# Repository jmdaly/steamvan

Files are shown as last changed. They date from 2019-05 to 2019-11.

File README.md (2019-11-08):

# SteamVan PCB

The SteamVan was developed as a MiniVan-compatible PCB based on an STM32MCU. It
does not support hot swap sockets, and it is designed such that the switches
are oriented such that the LEDs are South-facing.

## Overview

The SteamVan aims to meet the following design goals:

* Switches oriented such that the LEDs are South-facing, for
  compatibility with Cherry profile keycaps.

* USB Type-C support in both A to C and C to C configurations.

* QMK support.

* ESD protection circuitry, including data line protection and a
  polyfuse on the VCC line.

* Support for per-switch LED backlighting.

* Fits in MiniVan keyboard cases (tested with R3 MiniVan case only)

* RGB LED underglow support.

## Supported Layouts

The SteamVan supports the same layout options as the MiniVan.

## Obtaining the Files

This repository contains several submodules, which in turn contain
KiCad libraries used in the PCB design. In order to clone the SteamVan
repository, and all of the library submodules, the following command
must be issued,

```
git clone --recursive https://github.com/jmdaly/steamvan.git
```

## Acknowledgements

This project would not have been possible without all of the awesome work put
in by Evan Sailer of thevankeyboards.com. I own an R3 MiniVan and I love it. I
really like PCBs that have South-facing LEDs, USB-C connectors, and STM32
microcontrollers. As a result, I took on this project so that I could continue
to use the MiniVan layout, as well as my MiniVan case and keycaps, but have
some of the features that are important to me in a keyboard. I hope this work
is useful to other people.

There is an active keyboard design community on the MechKeys discord. The
users there have been very helpful, and I've learned a significant
amount about PCB design from them.

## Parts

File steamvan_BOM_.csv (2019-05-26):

References | Part | Value | Footprint | Quantity Per PCB | Digi-Key_PN | Datasheet | Description | LCSC PN | Product | Category | Status | Family | MPN | DK_Datasheet_Link | DK_Detail_Page | Manufacturer | Field8 | Field4 | Field7 | Field6 | Field5
C3 C4 C8 C9 C12 C13 C14 C15 C16 C17 C18 C19 C20 | C | 100n | C_0603_1608Metric | 13 |  | ~ | Unpolarized capacitor | C1590
C7 | C | 10n | C_0603_1608Metric | 1 |  | ~ | Unpolarized capacitor | C1589
C6 C10 C11 | C | 1u | C_0603_1608Metric | 3 |  | ~ | Unpolarized capacitor | C59782
C1 C2 | C | 30p | C_0603_1608Metric | 2 |  | ~ | Unpolarized capacitor | C22397
C5 | C | 4.7u | C_0603_1608Metric | 1 |  | ~ | Unpolarized capacitor | C19666
D1 D2 D3 D4 D5 D6 D7 D8 D9 D10 D11 D12 D13 D14 D15 D16 D17 D18 D19 D20 D21 D22 D23 D24 D25 D26 D27 D28 D29 D30 D31 D32 D33 D34 D35 D36 D37 D38 D39 D40 D41 D42 D43 D44 D45 D46 | D | D | D_SOD-123 | 46 |  | http://www.mccsemi.com/up_pdf/1N4148W(SOD123).pdf | Diode | C83528 | 1N4148W-TP
F1 | Polyfuse | 500mA | R_0805_2012Metric | 1 |  | ~ | Resettable fuse, polymeric positive temperature coefficient | C66452
J1 | Conn_01x05_Male | Conn_01x05_Male | PinHeader_1x05_P2.54mm_Vertical | 1 |  | ~ | Generic connector, single row, 01x05, script generated (kicad-library-utils/schlib/autogen/connector/)
K_FN1 K_LCTL1 K_RALT1 K_SUPER1 | MX-1.25U | MX-1.25U | MXOnly-1.25U | 4
K_FN2 K_FN4 K_RSHIFT1 | MX-1.5U | MX-1.5U | MXOnly-1.5U | 3
K_RALT2 | MX-1.5U | MX-1.5U | MXOnly-1.5U-FLIPPED | 1
K_BACK1 K_LSHIFT1 | MX-1.75U | MX-1.75U | MXOnly-1.75U | 2
K_LOCK1 | MX-1U | MX-1.75U | MXOnly-1.75U | 1
K_,1 K_.1 K_/1 K_;1 K_A1 K_B1 K_C1 K_D1 K_DOWN1 K_E1 K_F1 K_FN3 K_FN4_2 K_G1 K_H1 K_I1 K_J1 K_K1 K_L1 K_LALT1 K_M1 K_N1 K_O1 K_P1 K_Q1 K_R1 K_S1 K_T1 K_TAB1 K_U1 K_V1 K_W1 K_X1 K_Y1 K_Z1 | MX-1U | MX-1U | MXOnly-1U | 35
K_LCTL2 K_SUPER2 | MX-1U | MX-1U | MXOnly-1U-FLIPPED | 2
K_RIGHT1 | MX-1.75U | MX-1U | MXOnly-1U | 1
K_ENTER1 | MX-2.25U | MX-2.25U | MXOnly-2.25U-ReversedStabilizers | 1
K_SPACE1 | MX-2U | MX-2U | MXOnly-2U-ReversedStabilizers | 1
Q1 | FMMT493TA | FMMT493TA | SOT-23-3 | 1 | FMMT493CT-ND | https://www.diodes.com/assets/Datasheets/FMMT493.pdf | TRANS NPN 100V 1A SOT23-3 | C47296 |  | Discrete Semiconductor Products | Active | Transistors - Bipolar (BJT) - Single | FMMT493TA | https://www.diodes.com/assets/Datasheets/FMMT493.pdf | /product-detail/en/diodes-incorporated/FMMT493TA/FMMT493CT-ND/92663 | Diodes Incorporated
R1 R2 R3 R4 R5 R6 R7 R8 R9 R10 R11 R12 R13 R14 R15 R16 R17 R18 R19 R20 R21 R22 R23 R24 R25 R26 R27 R28 R29 R30 R31 R32 R33 R34 R35 R36 R37 R38 R39 R40 R41 R42 R43 R44 R45 R46 | R_Small | 560 | R_0603_1608Metric | 46 |  | ~ | Resistor, small symbol
RC8 | R | 10k | R_0603_1608Metric | 1 |  | ~ | Resistor | C98220
RC1 RC9 | R | 470 | R_0603_1608Metric | 2 |  | ~ | Resistor | C114433
RC6 RC7 | R | 5.1k | R_0603_1608Metric | 2 |  | ~ | Resistor | C14677
RGB1 RGB2 RGB3 RGB4 RGB5 RGB6 RGB7 RGB8 RGB9 | WS2812B | WS2812B | LED_WS2812B_PLCC4_5.0x5.0mm_P3.2mm | 9 |  | https://cdn-shop.adafruit.com/datasheets/WS2812B.pdf | RGB LED with integrated controller | C114585
SW1 | SW_Push | SW_Push | SW_SPST_TL3342 | 1 |  |  | Push button switch, generic, two pins | C92584
U4 | 74LVC1G34 | 74LVC1G34 | SOT-353_SC-70-5 | 1 |  |  |  | C94111
U3 | NUF2221W1T2G | NUF2221W1T2G | SOT-363 | 1 |  | Good |  | C274624 |  |  |  |  |  |  |  |  | ON Semiconductor | SOT-363 ON Semiconductor | NUF2221W1T2G Series 8 V USB Upstream Terminator with ESD Protection - SC-88 | 0.27 USD | NUF2221W1T2G
U1 | STM32F303CBTx | STM32F303CBTx | LQFP-48_7x7mm_P0.5mm | 1 |  | http://www.st.com/st-web-ui/static/active/en/resource/technical/document/datasheet/DM00058181.pdf | ARM Cortex-M4 MCU, 128KB flash, 32KB RAM, 72MHz, 2-3.6V, 37 GPIO, LQFP-48 | C108516
U2 | TLV70233_SOT23-5 | TLV70233_SOT23-5 | SOT-23-5 | 1 |  | http://www.ti.com/lit/ds/symlink/tlv702.pdf | 300 mA Low Dropout Voltage Regulator, Fixed Output 3.3V, SOT-23-5 | C26833
USB1 | HRO-TYPE-C-31-M-12 | HRO-TYPE-C-31-M-12 | HRO-TYPE-C-31-M-12-Assembly | 1 |  |  |  | C165948
Y1 | Crystal_GND24 | 8MHz | Crystal_SMD_5032-4Pin_5.0x3.2mm | 1 |  | ~ | Four pin crystal, GND on pins 2 and 4 | C133333
Component Groups: | 31
Component Count: | 187
Fitted Components: | 187
Number of PCBs: | 1
Total components: | 187
Schematic Version:
Schematic Date:
BoM Date: | Sat 25 May 2019 10:14:55 PM EDT
Schematic Source: | /home/jmdaly/git/steamvan/steamvan.sch
KiCad Version: | Eeschema 5.0.2-bee76a0~70~ubuntu16.04.1

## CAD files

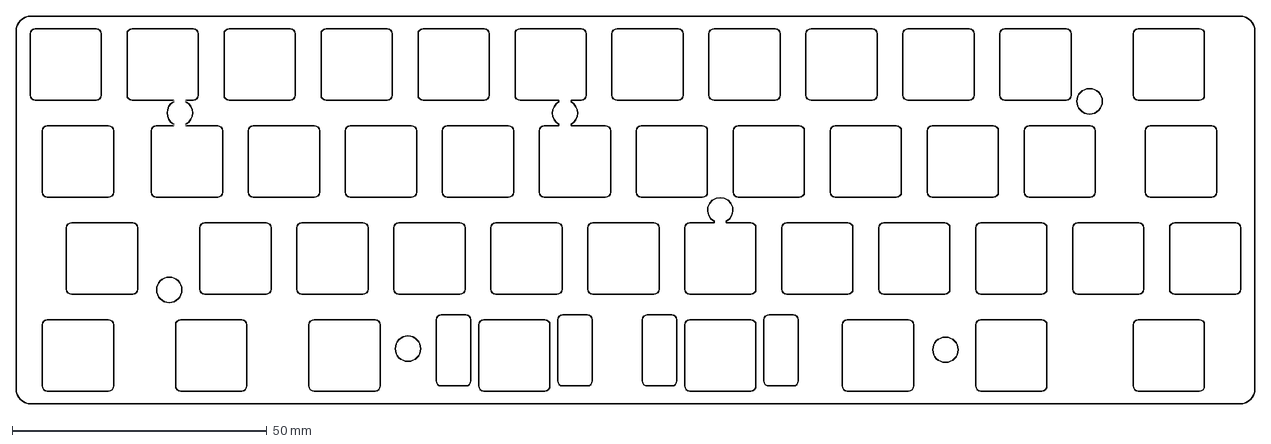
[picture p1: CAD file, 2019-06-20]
plates/standard_plate.dxf
243.4 x 76.2 mm

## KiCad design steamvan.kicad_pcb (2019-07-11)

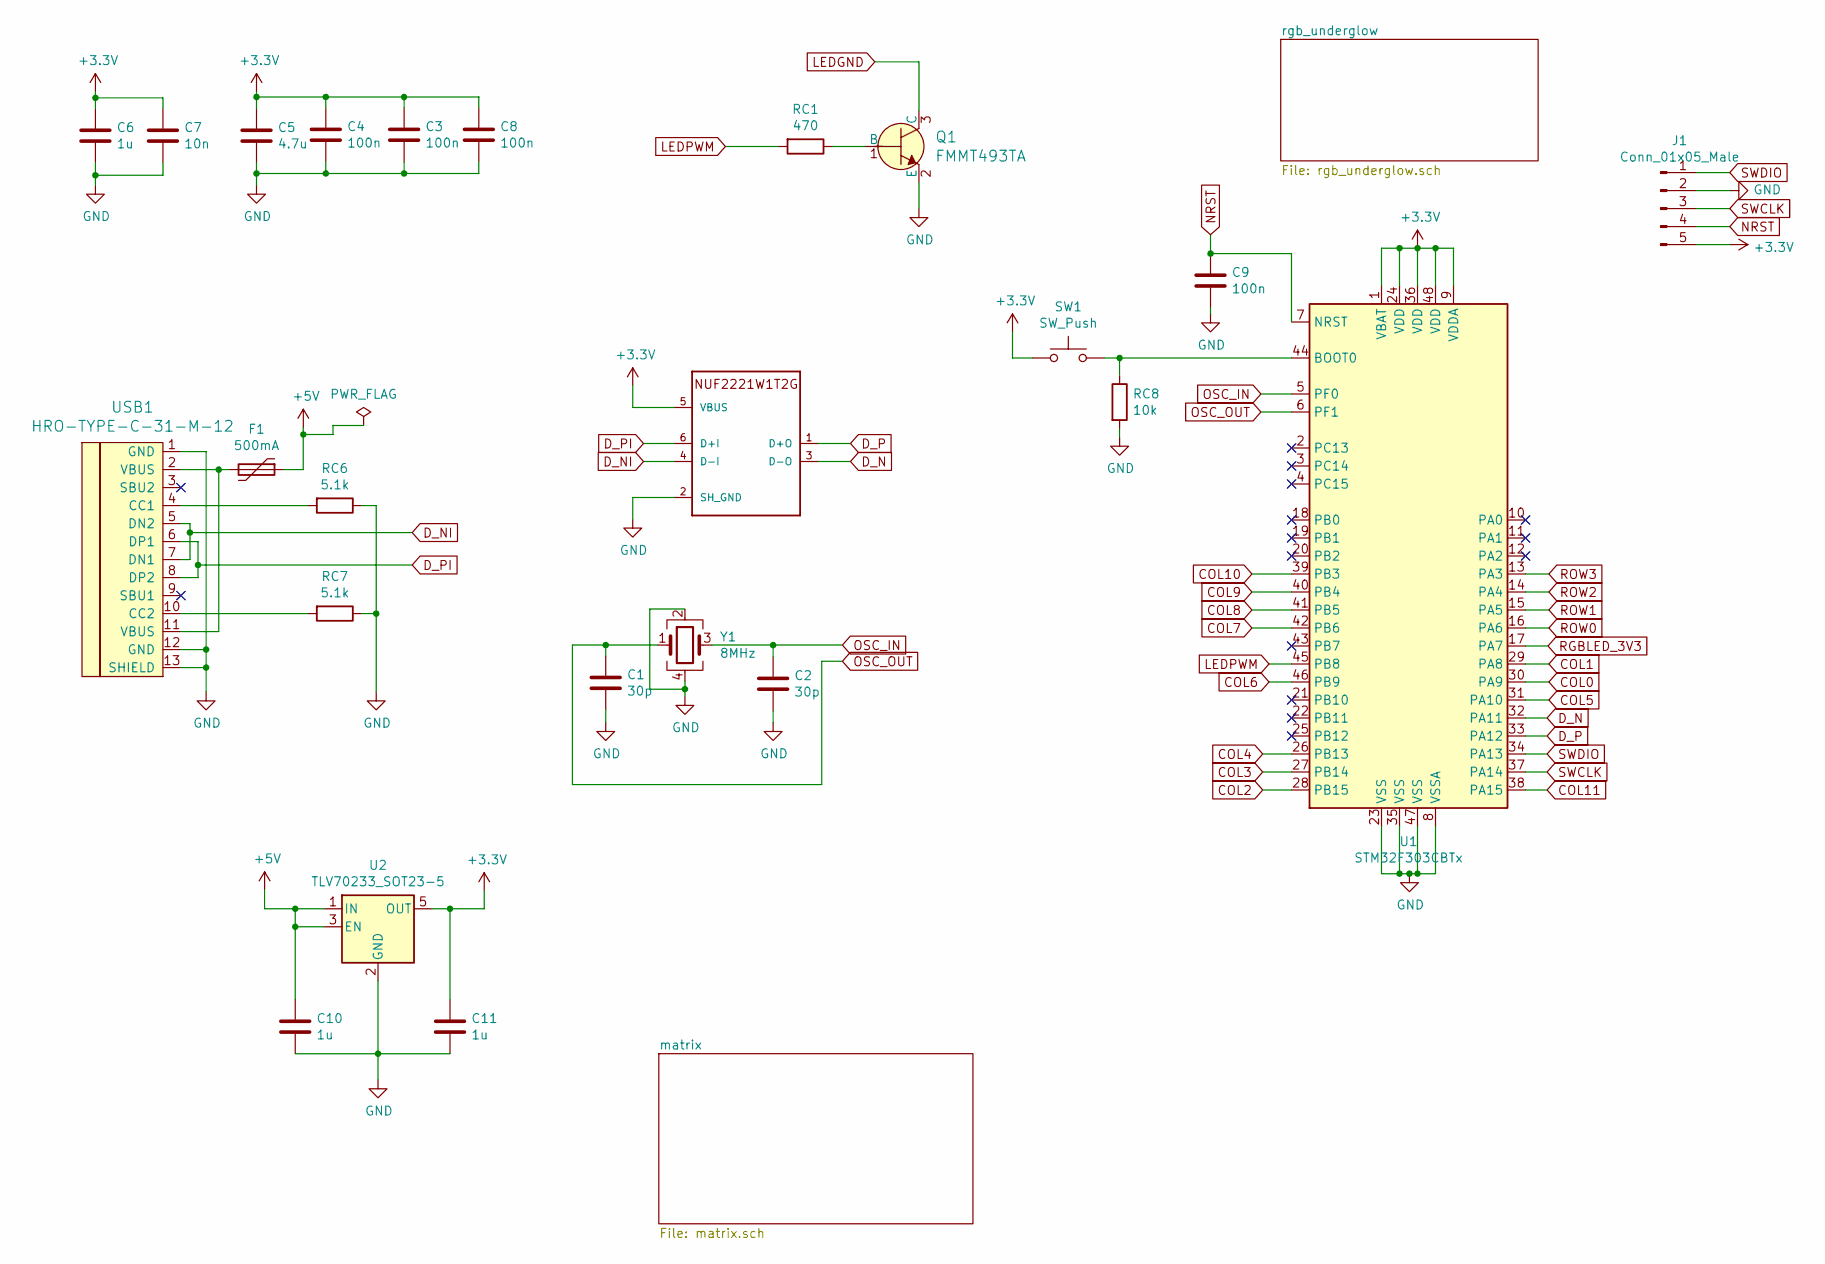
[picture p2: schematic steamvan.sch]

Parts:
C1, C2: 30p; C_0603_1608Metric; LCSC PN C22397
C3, C4, C8, C9: 100n; C_0603_1608Metric; LCSC PN C1590
C5: 4.7u; C_0603_1608Metric; LCSC PN C19666
C6, C10, C11: 1u; C_0603_1608Metric; LCSC PN C59782
C7: 10n; C_0603_1608Metric; LCSC PN C1589
F1: 500mA; R_0805_2012Metric; LCSC PN C66452
J1: Conn_01x05_Male; PinHeader_1x05_P2.54mm_Vertical
Q1: FMMT493TA; SOT-23-3; MPN FMMT493TA; Digi-Key_PN FMMT493CT-ND
RC1: 470; R_0603_1608Metric
RC6, RC7: 5.1k; R_0603_1608Metric; LCSC PN C14677
RC8: 10k; R_0603_1608Metric; LCSC PN C98220
SW1: SW_Push; SW_SPST_TL3342; LCSC PN C92584
U1: STM32F303CBTx; LQFP-48_7x7mm_P0.5mm; LCSC PN C108516
U2: TLV70233_SOT23-5; SOT-23-5; LCSC PN C26833
U3: NUF2221W1T2G; SOT-363; LCSC PN C274624
USB1: HRO-TYPE-C-31-M-12; HRO-TYPE-C-31-M-12-Assembly; LCSC PN C165948
Y1: 8MHz; Crystal_SMD_5032-4Pin_5.0x3.2mm; LCSC PN C133333

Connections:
+3V3: C3.1, C4.1, C5.1, C6.1, C7.1, C8.1, C11.1, J1.5, SW1.1, U1.1 (VBAT), U1.9 (VDDA), U1.24 (VDD), U1.36 (VDD), U1.48 (VDD), U2.5 (OUT), U3.5 (VBUS)
+5V: C10.1, F1.1, U2.1 (IN), U2.3 (EN); also elsewhere on the board
COL0: U1.30 (PA9); also elsewhere on the board
COL1: U1.29 (PA8); also elsewhere on the board
COL2: U1.28 (PB15); also elsewhere on the board
COL3: U1.27 (PB14); also elsewhere on the board
COL4: U1.26 (PB13); also elsewhere on the board
COL5: U1.31 (PA10); also elsewhere on the board
COL6: U1.46 (PB9); also elsewhere on the board
COL7: U1.42 (PB6); also elsewhere on the board
COL8: U1.41 (PB5); also elsewhere on the board
COL9: U1.40 (PB4); also elsewhere on the board
COL10: U1.39 (PB3); also elsewhere on the board
COL11: U1.38 (PA15); also elsewhere on the board
D_N: U1.32 (PA11), U3.3 (D-O)
D_NI: U3.4 (D-I), USB1.5 (DN2), USB1.7 (DN1)
D_P: U1.33 (PA12), U3.1 (D+O)
D_PI: U3.6 (D+I), USB1.6 (DP1), USB1.8 (DP2)
GND: C1.2, C2.2, C3.2, C4.2, C5.2, C6.2, C7.2, C8.2, C9.2, C10.2, C11.2, J1.2, Q1.2 (E), RC6.1, RC7.1, RC8.2, U1.8 (VSSA), U1.23 (VSS), U1.35 (VSS), U1.47 (VSS), U2.2 (GND), U3.2 (SH_GND), USB1.1 (GND), USB1.12 (GND), USB1.13 (SHIELD), Y1.2, Y1.4; also elsewhere on the board
LEDGND: Q1.3 (C); also elsewhere on the board
LEDPWM: RC1.2, U1.45 (PB8)
NRST: C9.1, J1.4, U1.7 (NRST)
unnamed: F1.2, USB1.2 (VBUS), USB1.11 (VBUS)
unnamed: Q1.1 (B), RC1.1
unnamed: RC6.2, USB1.4 (CC1)
unnamed: RC7.2, USB1.10 (CC2)
unnamed: RC8.1, SW1.2, U1.44 (BOOT0)
OSC_IN: C2.1, U1.5 (PF0), Y1.3
OSC_OUT: C1.1, U1.6 (PF1), Y1.1
RGBLED_3V3: U1.17 (PA7); also elsewhere on the board
ROW0: U1.16 (PA6); also elsewhere on the board
ROW1: U1.15 (PA5); also elsewhere on the board
ROW2: U1.14 (PA4); also elsewhere on the board
ROW3: U1.13 (PA3); also elsewhere on the board
SWCLK: J1.3, U1.37 (PA14)
SWDIO: J1.1, U1.34 (PA13)

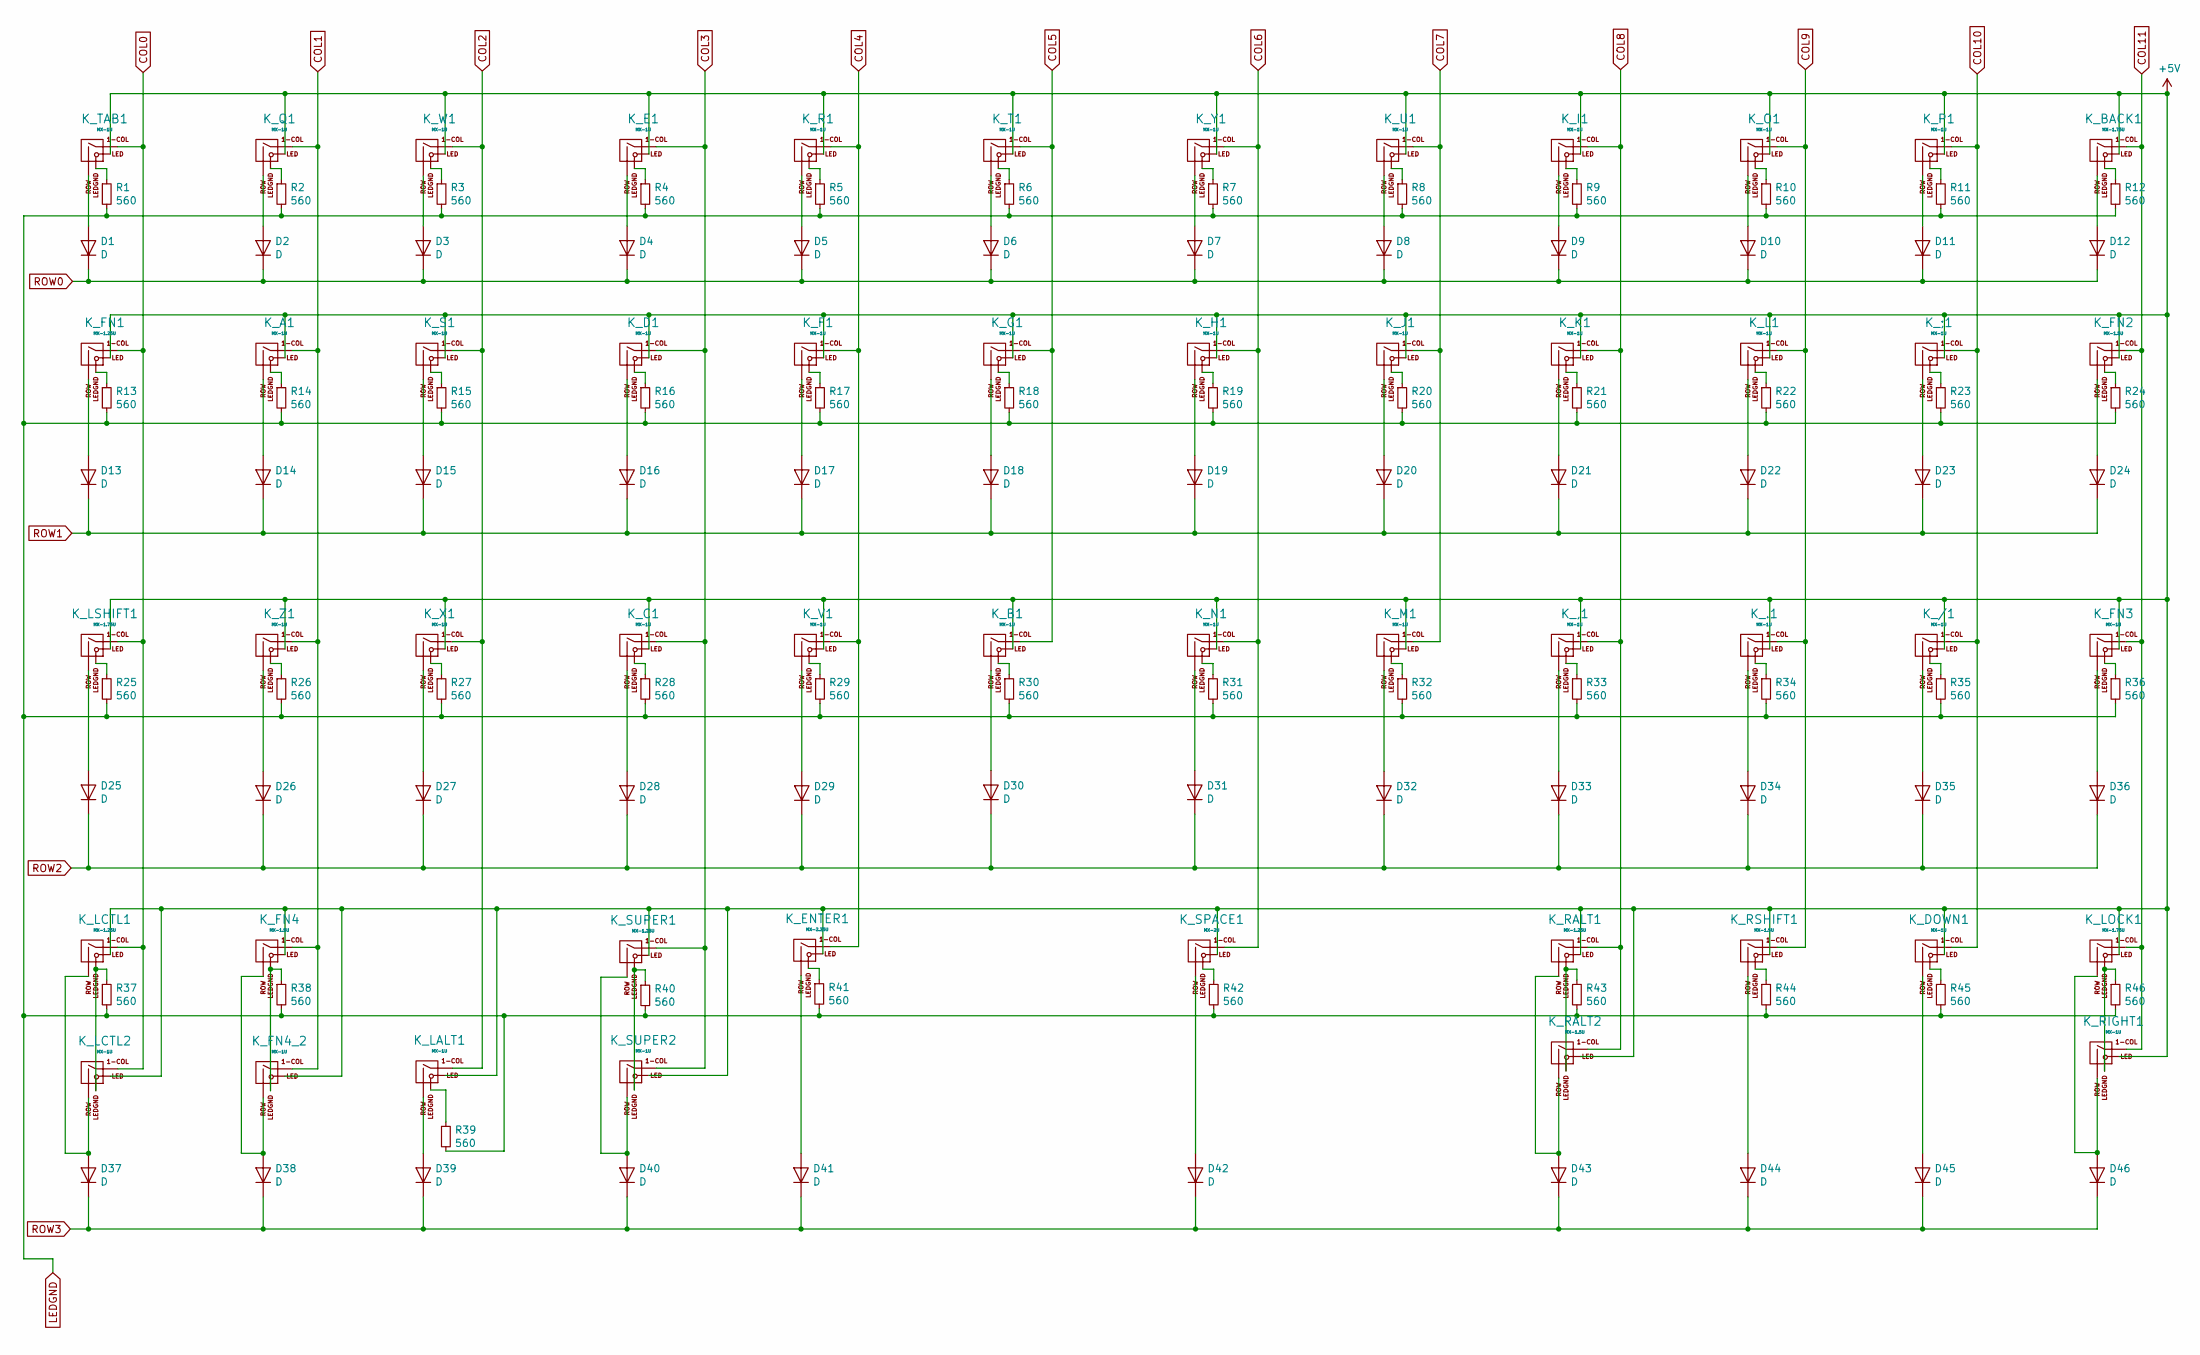
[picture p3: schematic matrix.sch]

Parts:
D1, D2, D3, D4, D5, D6, D7, D8, D9, D10, D11, D12, D13, D14, D15, D16, D17, D18, D19, D20, D21, D22, D23, D24, D25, D26, D27, D28, D29, D30, D31, D32, D33, D34, D35, D36, D37, D38, D39, D40, D41, D42, D43, D44, D45, D46: D; D_SOD-123; LCSC PN C83528
K_,1: MX-1U; MXOnly-1U
K_.1: MX-1U; MXOnly-1U
K_/1: MX-1U; MXOnly-1U
K_;1: MX-1U; MXOnly-1U
K_A1: MX-1U; MXOnly-1U
K_B1: MX-1U; MXOnly-1U
K_BACK1: MX-1.75U; MXOnly-1.75U
K_C1: MX-1U; MXOnly-1U
K_D1: MX-1U; MXOnly-1U
K_DOWN1: MX-1U; MXOnly-1U
K_E1: MX-1U; MXOnly-1U
K_ENTER1: MX-2.25U; MXOnly-2.25U-ReversedStabilizers
K_F1: MX-1U; MXOnly-1U
K_FN1: MX-1.25U; MXOnly-1.25U
K_FN2, K_FN4: MX-1.5U; MXOnly-1.5U
K_FN3, K_FN4_2: MX-1U; MXOnly-1U
K_G1: MX-1U; MXOnly-1U
K_H1: MX-1U; MXOnly-1U
K_I1: MX-1U; MXOnly-1U
K_J1: MX-1U; MXOnly-1U
K_K1: MX-1U; MXOnly-1U
K_L1: MX-1U; MXOnly-1U
K_LALT1: MX-1U; MXOnly-1U
K_LCTL1: MX-1.25U; MXOnly-1.25U
K_LCTL2: MX-1U; MXOnly-1U-FLIPPED
K_LOCK1: MX-1.75U; MXOnly-1.75U
K_LSHIFT1: MX-1.75U; MXOnly-1.75U
K_M1: MX-1U; MXOnly-1U
K_N1: MX-1U; MXOnly-1U
K_O1: MX-1U; MXOnly-1U
K_P1: MX-1U; MXOnly-1U
K_Q1: MX-1U; MXOnly-1U
K_R1: MX-1U; MXOnly-1U
K_RALT1: MX-1.25U; MXOnly-1.25U
K_RALT2: MX-1.5U; MXOnly-1.5U-FLIPPED
K_RIGHT1: MX-1U; MXOnly-1U
K_RSHIFT1: MX-1.5U; MXOnly-1.5U
K_S1: MX-1U; MXOnly-1U
K_SPACE1: MX-2U; MXOnly-2U-ReversedStabilizers
K_SUPER1: MX-1.25U; MXOnly-1.25U
K_SUPER2: MX-1U; MXOnly-1U-FLIPPED
K_T1: MX-1U; MXOnly-1U
K_TAB1: MX-1U; MXOnly-1U
K_U1: MX-1U; MXOnly-1U
K_V1: MX-1U; MXOnly-1U
K_W1: MX-1U; MXOnly-1U
K_X1: MX-1U; MXOnly-1U
K_Y1: MX-1U; MXOnly-1U
K_Z1: MX-1U; MXOnly-1U
R1, R2, R3, R4, R5, R6, R7, R8, R9, R10, R11, R12, R13, R14, R15, R16, R17, R18, R19, R20, R21, R22, R23, R24, R25, R26, R27, R28, R29, R30, R31, R32, R33, R34, R35, R36, R37, R38, R39, R40, R41, R42, R43, R44, R45, R46: 560; R_0603_1608Metric

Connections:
+5V: K_,1.3 (LED), K_.1.3 (LED), K_/1.3 (LED), K_;1.3 (LED), K_A1.3 (LED), K_B1.3 (LED), K_BACK1.3 (LED), K_C1.3 (LED), K_D1.3 (LED), K_DOWN1.3 (LED), K_E1.3 (LED), K_ENTER1.3 (LED), K_F1.3 (LED), K_FN1.3 (LED), K_FN2.3 (LED), K_FN3.3 (LED), K_FN4.3 (LED), K_FN4_2.3 (LED), K_G1.3 (LED), K_H1.3 (LED), K_I1.3 (LED), K_J1.3 (LED), K_K1.3 (LED), K_L1.3 (LED), K_LALT1.3 (LED), K_LCTL1.3 (LED), K_LCTL2.3 (LED), K_LOCK1.3 (LED), K_LSHIFT1.3 (LED), K_M1.3 (LED), K_N1.3 (LED), K_O1.3 (LED), K_P1.3 (LED), K_Q1.3 (LED), K_R1.3 (LED), K_RALT1.3 (LED), K_RALT2.3 (LED), K_RIGHT1.3 (LED), K_RSHIFT1.3 (LED), K_S1.3 (LED), K_SPACE1.3 (LED), K_SUPER1.3 (LED), K_SUPER2.3 (LED), K_T1.3 (LED), K_TAB1.3 (LED), K_U1.3 (LED), K_V1.3 (LED), K_W1.3 (LED), K_X1.3 (LED), K_Y1.3 (LED), K_Z1.3 (LED); also elsewhere on the board
COL0: K_FN1.1 (COL), K_LCTL1.1 (COL), K_LCTL2.1 (COL), K_LSHIFT1.1 (COL), K_TAB1.1 (COL); also elsewhere on the board
COL1: K_A1.1 (COL), K_FN4.1 (COL), K_FN4_2.1 (COL), K_Q1.1 (COL), K_Z1.1 (COL); also elsewhere on the board
COL2: K_LALT1.1 (COL), K_S1.1 (COL), K_W1.1 (COL), K_X1.1 (COL); also elsewhere on the board
COL3: K_C1.1 (COL), K_D1.1 (COL), K_E1.1 (COL), K_SUPER1.1 (COL), K_SUPER2.1 (COL); also elsewhere on the board
COL4: K_ENTER1.1 (COL), K_F1.1 (COL), K_R1.1 (COL), K_V1.1 (COL); also elsewhere on the board
COL5: K_B1.1 (COL), K_G1.1 (COL), K_T1.1 (COL); also elsewhere on the board
COL6: K_H1.1 (COL), K_N1.1 (COL), K_SPACE1.1 (COL), K_Y1.1 (COL); also elsewhere on the board
COL7: K_J1.1 (COL), K_M1.1 (COL), K_U1.1 (COL); also elsewhere on the board
COL8: K_,1.1 (COL), K_I1.1 (COL), K_K1.1 (COL), K_RALT1.1 (COL), K_RALT2.1 (COL); also elsewhere on the board
COL9: K_.1.1 (COL), K_L1.1 (COL), K_O1.1 (COL), K_RSHIFT1.1 (COL); also elsewhere on the board
COL10: K_/1.1 (COL), K_;1.1 (COL), K_DOWN1.1 (COL), K_P1.1 (COL); also elsewhere on the board
COL11: K_BACK1.1 (COL), K_FN2.1 (COL), K_FN3.1 (COL), K_LOCK1.1 (COL), K_RIGHT1.1 (COL); also elsewhere on the board
LEDGND: R1.2, R2.2, R3.2, R4.2, R5.2, R6.2, R7.2, R8.2, R9.2, R10.2, R11.2, R12.2, R13.2, R14.2, R15.2, R16.2, R17.2, R18.2, R19.2, R20.2, R21.2, R22.2, R23.2, R24.2, R25.2, R26.2, R27.2, R28.2, R29.2, R30.2, R31.2, R32.2, R33.2, R34.2, R35.2, R36.2, R37.2, R38.2, R39.2, R40.2, R41.2, R42.2, R43.2, R44.2, R45.2, R46.2; also elsewhere on the board
unnamed: D1.2 (A), K_TAB1.2 (ROW)
unnamed: D2.2 (A), K_Q1.2 (ROW)
unnamed: D3.2 (A), K_W1.2 (ROW)
unnamed: D4.2 (A), K_E1.2 (ROW)
unnamed: D5.2 (A), K_R1.2 (ROW)
unnamed: D6.2 (A), K_T1.2 (ROW)
unnamed: D7.2 (A), K_Y1.2 (ROW)
unnamed: D8.2 (A), K_U1.2 (ROW)
unnamed: D9.2 (A), K_I1.2 (ROW)
unnamed: D10.2 (A), K_O1.2 (ROW)
unnamed: D11.2 (A), K_P1.2 (ROW)
unnamed: D12.2 (A), K_BACK1.2 (ROW)
unnamed: D13.2 (A), K_FN1.2 (ROW)
unnamed: D14.2 (A), K_A1.2 (ROW)
unnamed: D15.2 (A), K_S1.2 (ROW)
unnamed: D16.2 (A), K_D1.2 (ROW)
unnamed: D17.2 (A), K_F1.2 (ROW)
unnamed: D18.2 (A), K_G1.2 (ROW)
unnamed: D19.2 (A), K_H1.2 (ROW)
unnamed: D20.2 (A), K_J1.2 (ROW)
unnamed: D21.2 (A), K_K1.2 (ROW)
unnamed: D22.2 (A), K_L1.2 (ROW)
unnamed: D23.2 (A), K_;1.2 (ROW)
unnamed: D24.2 (A), K_FN2.2 (ROW)
unnamed: D25.2 (A), K_LSHIFT1.2 (ROW)
unnamed: D26.2 (A), K_Z1.2 (ROW)
unnamed: D27.2 (A), K_X1.2 (ROW)
unnamed: D28.2 (A), K_C1.2 (ROW)
unnamed: D29.2 (A), K_V1.2 (ROW)
unnamed: D30.2 (A), K_B1.2 (ROW)
unnamed: D31.2 (A), K_N1.2 (ROW)
unnamed: D32.2 (A), K_M1.2 (ROW)
unnamed: D33.2 (A), K_,1.2 (ROW)
unnamed: D34.2 (A), K_.1.2 (ROW)
unnamed: D35.2 (A), K_/1.2 (ROW)
unnamed: D36.2 (A), K_FN3.2 (ROW)
unnamed: D37.2 (A), K_LCTL1.2 (ROW), K_LCTL2.2 (ROW)
unnamed: D38.2 (A), K_FN4.2 (ROW), K_FN4_2.2 (ROW)
unnamed: D39.2 (A), K_LALT1.2 (ROW)
unnamed: D40.2 (A), K_SUPER1.2 (ROW), K_SUPER2.2 (ROW)
unnamed: D41.2 (A), K_ENTER1.2 (ROW)
unnamed: D42.2 (A), K_SPACE1.2 (ROW)
unnamed: D43.2 (A), K_RALT1.2 (ROW), K_RALT2.2 (ROW)
unnamed: D44.2 (A), K_RSHIFT1.2 (ROW)
unnamed: D45.2 (A), K_DOWN1.2 (ROW)
unnamed: D46.2 (A), K_LOCK1.2 (ROW), K_RIGHT1.2 (ROW)
unnamed: K_,1.4 (LEDGND), R33.1
unnamed: K_.1.4 (LEDGND), R34.1
unnamed: K_/1.4 (LEDGND), R35.1
unnamed: K_;1.4 (LEDGND), R23.1
unnamed: K_A1.4 (LEDGND), R14.1
unnamed: K_B1.4 (LEDGND), R30.1
unnamed: K_BACK1.4 (LEDGND), R12.1
unnamed: K_C1.4 (LEDGND), R28.1
unnamed: K_D1.4 (LEDGND), R16.1
unnamed: K_DOWN1.4 (LEDGND), R45.1
unnamed: K_E1.4 (LEDGND), R4.1
unnamed: K_ENTER1.4 (LEDGND), R41.1
unnamed: K_F1.4 (LEDGND), R17.1
unnamed: K_FN1.4 (LEDGND), R13.1
unnamed: K_FN2.4 (LEDGND), R24.1
unnamed: K_FN3.4 (LEDGND), R36.1
unnamed: K_FN4.4 (LEDGND), K_FN4_2.4 (LEDGND), R38.1
unnamed: K_G1.4 (LEDGND), R18.1
unnamed: K_H1.4 (LEDGND), R19.1
unnamed: K_I1.4 (LEDGND), R9.1
unnamed: K_J1.4 (LEDGND), R20.1
unnamed: K_K1.4 (LEDGND), R21.1
unnamed: K_L1.4 (LEDGND), R22.1
unnamed: K_LALT1.4 (LEDGND), R39.1
unnamed: K_LCTL1.4 (LEDGND), K_LCTL2.4 (LEDGND), R37.1
unnamed: K_LOCK1.4 (LEDGND), K_RIGHT1.4 (LEDGND), R46.1
unnamed: K_LSHIFT1.4 (LEDGND), R25.1
unnamed: K_M1.4 (LEDGND), R32.1
unnamed: K_N1.4 (LEDGND), R31.1
unnamed: K_O1.4 (LEDGND), R10.1
unnamed: K_P1.4 (LEDGND), R11.1
unnamed: K_Q1.4 (LEDGND), R2.1
unnamed: K_R1.4 (LEDGND), R5.1
unnamed: K_RALT1.4 (LEDGND), K_RALT2.4 (LEDGND), R43.1
unnamed: K_RSHIFT1.4 (LEDGND), R44.1
unnamed: K_S1.4 (LEDGND), R15.1
unnamed: K_SPACE1.4 (LEDGND), R42.1
unnamed: K_SUPER1.4 (LEDGND), K_SUPER2.4 (LEDGND), R40.1
unnamed: K_T1.4 (LEDGND), R6.1
unnamed: K_TAB1.4 (LEDGND), R1.1
unnamed: K_U1.4 (LEDGND), R8.1
unnamed: K_V1.4 (LEDGND), R29.1
unnamed: K_W1.4 (LEDGND), R3.1
unnamed: K_X1.4 (LEDGND), R27.1
unnamed: K_Y1.4 (LEDGND), R7.1
unnamed: K_Z1.4 (LEDGND), R26.1
ROW0: D1.1 (K), D2.1 (K), D3.1 (K), D4.1 (K), D5.1 (K), D6.1 (K), D7.1 (K), D8.1 (K), D9.1 (K), D10.1 (K), D11.1 (K), D12.1 (K); also elsewhere on the board
ROW1: D13.1 (K), D14.1 (K), D15.1 (K), D16.1 (K), D17.1 (K), D18.1 (K), D19.1 (K), D20.1 (K), D21.1 (K), D22.1 (K), D23.1 (K), D24.1 (K); also elsewhere on the board
ROW2: D25.1 (K), D26.1 (K), D27.1 (K), D28.1 (K), D29.1 (K), D30.1 (K), D31.1 (K), D32.1 (K), D33.1 (K), D34.1 (K), D35.1 (K), D36.1 (K); also elsewhere on the board
ROW3: D37.1 (K), D38.1 (K), D39.1 (K), D40.1 (K), D41.1 (K), D42.1 (K), D43.1 (K), D44.1 (K), D45.1 (K), D46.1 (K); also elsewhere on the board

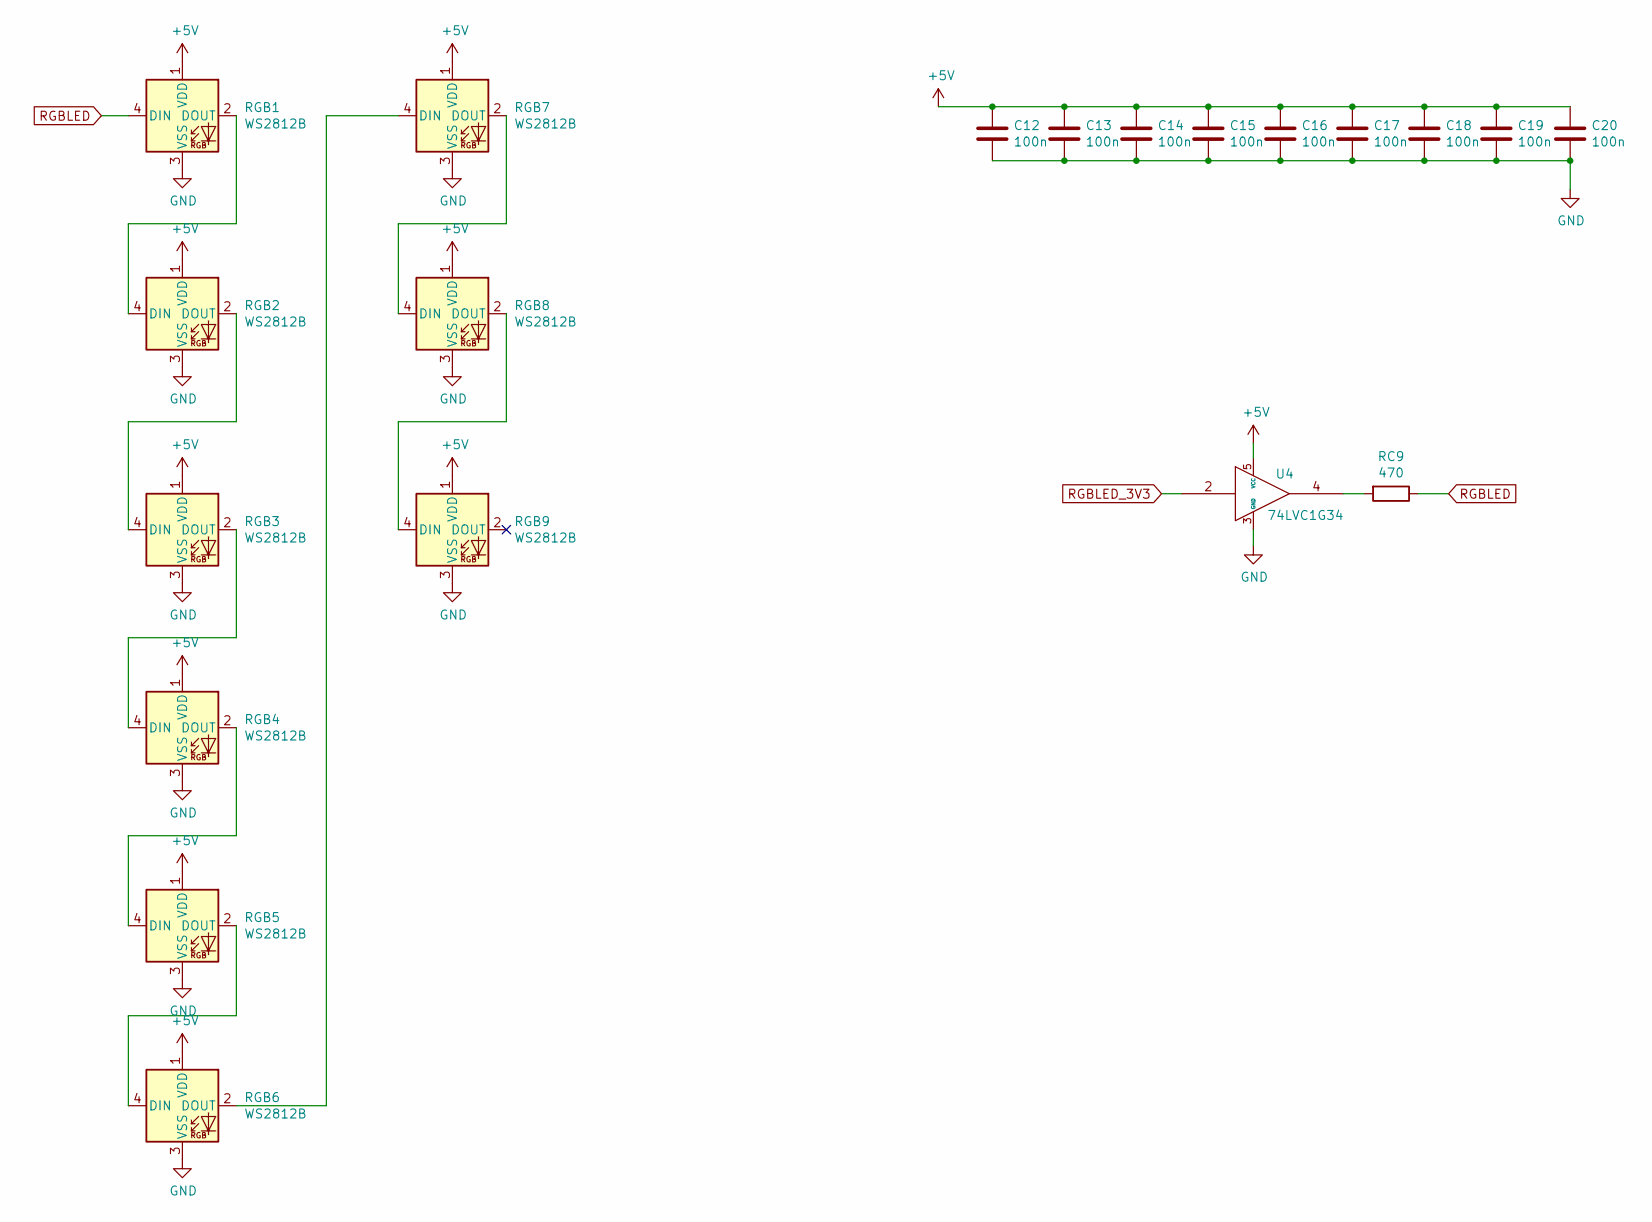
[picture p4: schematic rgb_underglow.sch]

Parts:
C12, C13, C14, C15, C16, C17, C18, C19, C20: 100n; C_0603_1608Metric; LCSC PN C1590
RC9: 470; R_0603_1608Metric; LCSC PN C114433
RGB1, RGB2, RGB3, RGB4, RGB5, RGB6, RGB7, RGB8, RGB9: WS2812B; LED_WS2812B_PLCC4_5.0x5.0mm_P3.2mm; LCSC PN C114585
U4: 74LVC1G34; SOT-353_SC-70-5; LCSC PN C94111

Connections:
+5V: C12.1, C13.1, C14.1, C15.1, C16.1, C17.1, C18.1, C19.1, C20.1, RGB1.1 (VDD), RGB2.1 (VDD), RGB3.1 (VDD), RGB4.1 (VDD), RGB5.1 (VDD), RGB6.1 (VDD), RGB7.1 (VDD), RGB8.1 (VDD), RGB9.1 (VDD), U4.5 (VCC); also elsewhere on the board
GND: C12.2, C13.2, C14.2, C15.2, C16.2, C17.2, C18.2, C19.2, C20.2, RGB1.3 (VSS), RGB2.3 (VSS), RGB3.3 (VSS), RGB4.3 (VSS), RGB5.3 (VSS), RGB6.3 (VSS), RGB7.3 (VSS), RGB8.3 (VSS), RGB9.3 (VSS), U4.3 (GND); also elsewhere on the board
unnamed: RC9.2, U4.4
unnamed: RGB1.2 (DOUT), RGB2.4 (DIN)
unnamed: RGB2.2 (DOUT), RGB3.4 (DIN)
unnamed: RGB3.2 (DOUT), RGB4.4 (DIN)
unnamed: RGB4.2 (DOUT), RGB5.4 (DIN)
unnamed: RGB5.2 (DOUT), RGB6.4 (DIN)
unnamed: RGB6.2 (DOUT), RGB7.4 (DIN)
unnamed: RGB7.2 (DOUT), RGB8.4 (DIN)
unnamed: RGB8.2 (DOUT), RGB9.4 (DIN)
RGBLED: RC9.1, RGB1.4 (DIN)
RGBLED_3V3: U4.2; also elsewhere on the board

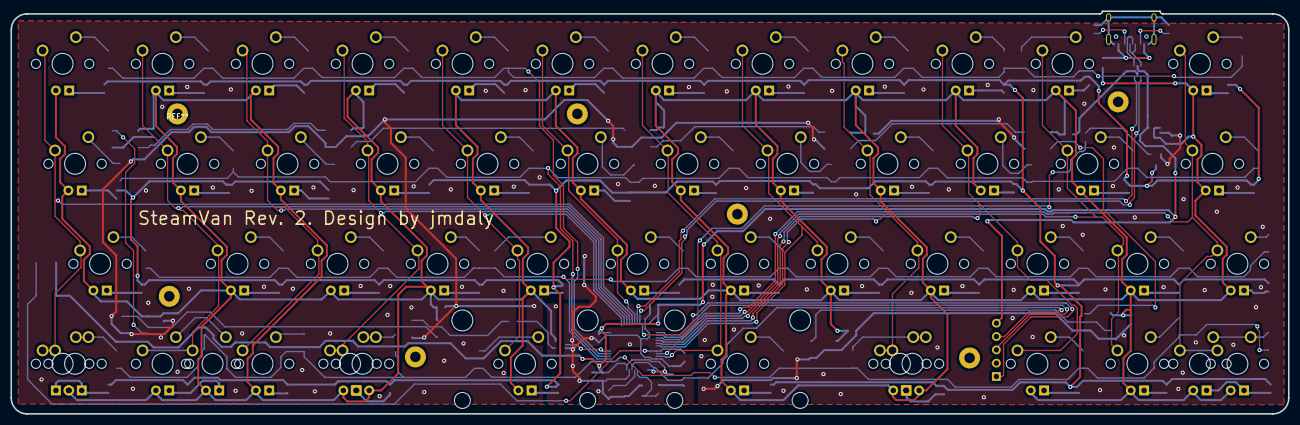
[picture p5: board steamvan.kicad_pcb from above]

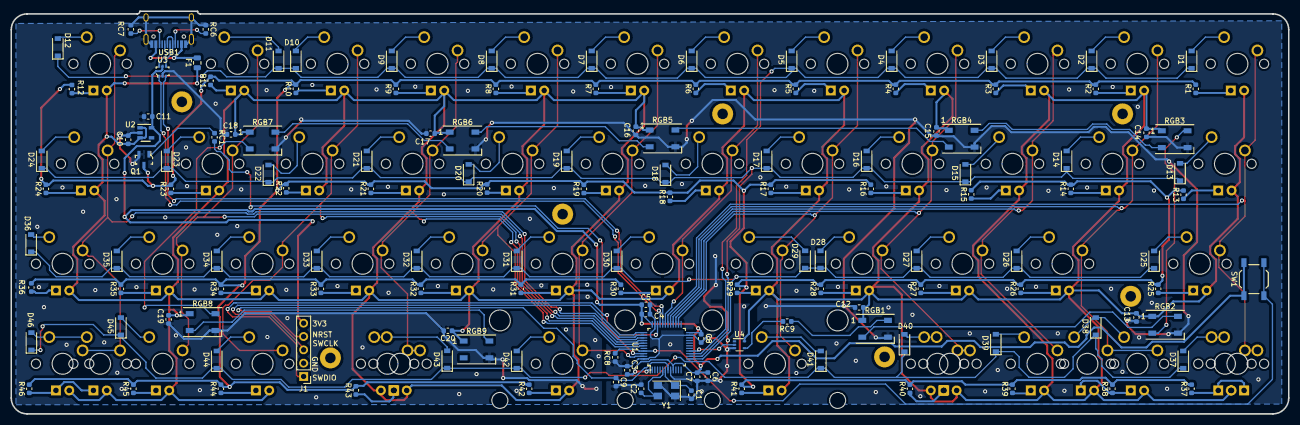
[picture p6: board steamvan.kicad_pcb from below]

Board: 2 copper layers, 243.4 x 76.7 mm, 187 parts (136 on the bottom side), 138 nets.

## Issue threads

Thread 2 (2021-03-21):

Firmware.

malinin24, 2021-03-21:
Hello.
Great job!
I want to assemble a cuatom numpad, came across your development, it will greatly speed up the process.
But I did not find a mention of the firmware.
Where can I get it? Are there sources?

jmdaly, 2021-03-23:
Hi there, thank you for checking out the project! This project runs on the QMK firmware. It's a popular open source keyboard firmware. You can find their site [here](https://qmk.fm/).  The particulars for the SteamVan in QMK can be found [here](https://github.com/qmk/qmk_firmware/tree/master/keyboards/handwired/steamvan). Hope that helps!

malinin24, 2021-03-23:
Cool!
Apparently I have not yet reached the QMK on stm32, now I saw it.
Many thanks again and success!

Closed 2021-03-23.

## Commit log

2018-12-23 Add: Initial commit of project structure
    [steamvan.kicad_pcb, steamvan.sch]
2018-12-23 Add: Digikey KiCAD library
2018-12-24 Update: Work on schematic
    [steamvan.sch]
2018-12-27 Update: Work on board schematix. Not done yet
    [matrix.sch, steamvan.sch]
2018-12-27 Update: Finish preliminary work on schematic
    Schematic still needs review, and my pin choices for the
    matrix should be double checked.
    [matrix.sch, steamvan.sch]
2019-01-20 Add: new minivan layouts, and start switching to MX/Alps hybrid footprints
    [matrix.sch, steamvan.kicad_pcb, steamvan.sch]
2019-01-20 Update: Work on PCB component placement
    [matrix.sch, steamvan.kicad_pcb]
2019-01-26 Update: Work on PCB layout
    [matrix.sch, steamvan.kicad_pcb]
2019-02-03 Add: PCB footprint
    [steamvan.kicad_pcb]
2019-02-04 Update: PCB footprint, and work on component placement
    [steamvan.kicad_pcb]
2019-02-05 Update: Work on routing
    [steamvan.kicad_pcb]
2019-02-13 Update: Add schematic components for RGB underglow, and work on routing
    [matrix.sch, rgb_underglow.sch, steamvan.kicad_pcb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]
2019-02-18 Update: Work on underglow
    [rgb_underglow.sch, steamvan.kicad_pcb]
2019-02-21 Update: More work on routing
    [steamvan.kicad_pcb]
2019-03-08 Update: More routing
    [steamvan.kicad_pcb]
2019-03-13 Update: Finish routing
    [steamvan.kicad_pcb]
2019-03-14 Update: Work on ground plane
    [steamvan.kicad_pcb]
2019-03-15 Update: Work on ground plane and exclusion around MCU
    [steamvan.kicad_pcb]
2019-03-18 Update: Routing improvements
    [steamvan.kicad_pcb]
2019-03-23 Update: More routing work
    [steamvan.kicad_pcb]
2019-03-23 Update: Work on routing and generate Gerbers
    [steamvan-B.Cu.gbl, steamvan-B.Mask.gbs, steamvan-B.Paste.gbp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]
2019-05-10 Update: Gerbers
    [steamvan-B.Cu.gbl, steamvan-B.Mask.gbs, steamvan-B.Paste.gbp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]
2019-05-15 Update: Move USB port location
    [steamvan-B.Cu.gbl, steamvan-B.Mask.gbs, steamvan-B.Paste.gbp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]
2019-05-16 Update: silk screen
    [steamvan-B.Cu.gbl, steamvan-B.Mask.gbs, steamvan-B.Paste.gbp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]
2019-05-17 Update: minor routing tweaks
    [steamvan-B.Cu.gbl, steamvan-B.Mask.gbs, steamvan-B.Paste.gbp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]
2019-05-22 Update: Regenerate Gerbers prior to sending off to production
    [steamvan-B.Cu.gbl, steamvan-B.Mask.gbs, steamvan-B.Paste.gbp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]
2019-05-22 Add: BOM
    [steamvan_BOM_.csv]
2019-05-26 Add: LCSC part numbers to schematic
    [steamvan.sch, steamvan_BOM_.csv]
2019-05-31 Update: Move components that may interfere with case
    [steamvan-B.Cu.gbl, steamvan-B.Mask.gbs, steamvan-B.Paste.gbp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]
2019-06-01 Update: Keep components out of the way of the case
    [steamvan-B.Cu.gbl, steamvan-B.Mask.gbs, steamvan-B.Paste.gbp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]
2019-06-10 Update: Begin moving RGB LEDs farther down
    I have done the three LEDs farthest from the USB port on the top row so
    far. Two more to go.
    [steamvan.kicad_pcb]
2019-06-11 Update: Move remaining RGB LEDs farther down to avoid case
    [steamvan-B.Cu.gbl, steamvan-B.Mask.gbs, steamvan-B.Paste.gbp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]
2019-06-18 Update: Move reset switch to line up better with case
    [steamvan-B.Cu.gbl, steamvan-B.Mask.gbs, steamvan-B.Paste.gbp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]
2019-06-20 Add: Initial standard plate
    [standard_plate.dxf]
2019-06-20 Update: Move reset switch in from edge a bit
    [steamvan-B.Cu.gbl, steamvan-B.Mask.gbs, steamvan-B.Paste.gbp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]
2019-06-27 Update: move programming headers - also regenerate Gerbers
    [steamvan-B.Cu.gbl, steamvan-B.Mask.gbs, steamvan-B.Paste.gbp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]
2019-06-27 Update: adjust top row RGB LEDs
    [steamvan-B.Cu.gbl, steamvan-B.Mask.gbs, steamvan-B.Paste.gbp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]
2019-07-09 Update: move programming jumper
    [steamvan-B.Cu.gbl, steamvan-B.Mask.gbs, steamvan-B.Paste.gbp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]
2019-07-11 Update: Move more components
    [steamvan-B.Cu.gbl, steamvan-B.Mask.gbs, steamvan-B.Paste.gbp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]
2019-08-03 Update: Gerbers and drill files
    [steamvan-B.Cu.gbl, steamvan-B.Mask.gbs, steamvan-B.Paste.gbp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]
